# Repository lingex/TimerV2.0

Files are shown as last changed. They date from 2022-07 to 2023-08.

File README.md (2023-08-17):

# TimerV2.0
A kittchen timer, mp3 player. STM32F103RET6, W25Q128, RX8025T, NS4168.  

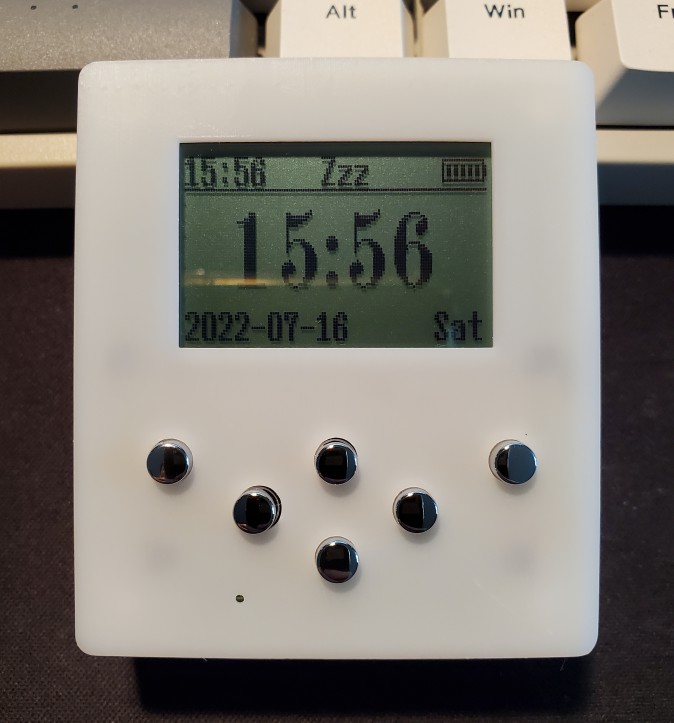
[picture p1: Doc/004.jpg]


## Feature
- software decode mp3, i2s output.  
- 16MB spi flash disk.  
- FATFS format.  
- DFU Bootloader.  

## Known issues  
- The USBLC6 (D1) will cost leakage when USB is not connect, can be avoid by disable the 'USB_EN' pin or simply cut the 5' pin of this component.  
- ~~USB disconnect interrupt can't be detected while device in sleep mode, may fix later.~~  
- ~~Sometimes return to main UI from the setting menu without expected, may fix later.~~  
- I2S stream CLK has to be set as a half of the real sample rate.  
- The NS4168 may cost about 2 mA current, not 1 uA provided by the datasheet.  

## Note  
- This mp3 decode solution is a limited demo, don't use for any business application.  
- More info can be found here:  
- TimerV2.0/TimerApp/Middlewares/ST/STM32_Audio/Codecs/SpiritDSP_MP3_Dec/Release_Notes.html  
- TimerV2.0/TimerApp/Middlewares/ST/STM32_Audio/Codecs/SpiritDSP_MP3_Dec/doc/SpiritMP3Dec_UG.pdf  

### About the '.dfu' file:  
- ST DFU device can be flash by DfuSe or STM32CubeProgrammer  
- The STM32CubeProgrammer supports both '.bin' and '.hex' file.  
- DfuSe supports '.dfu' file only, so you have to convert the '.bin' or '.hex' file into a '.dfu'.  
- To generate a '.dfu' file, there are some ways: like DfuFileMgr.exe(provide by ST), and some third-part tools like hex2dfu.exe.

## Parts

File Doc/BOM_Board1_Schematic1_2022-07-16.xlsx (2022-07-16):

No. | Quantity | Device | Designator | Footprint | Value
1 | 1 | 1056TR | BT1 | BAT-SMD_BD15.0-P18.80
2 | 17 | CAP_0603 | C1,C4,C5,C6,C9,C10,C12,C13,C14,C15,C16,C24,C25,C26,C27,C28,C29 | C0603 | 100nF
3 | 2 | CAP_0603 | C2,C3 | C0603 | 22pF
4 | 3 | CAP_0603 | C7,C11,C17 | C0603 | 1uF
5 | 1 | CAP_0805 | C8 | C0805 | 1uF
6 | 4 | CAP_0805 | C18,C19,C21,C23 | C0805 | 10uF
7 | 1 | C_Ele_SMD_5x5.4mm | C20 | CAP-SMD_BD5.0-L5.3-W5.3-LS6.3-FD | 100uF
8 | 1 | CAP_0805 | C22 | C0805 | 4.7uF
9 | 1 | USBLC6-2SC6 | D1 | SOT-23-6_L2.9-W1.6-P0.95-LS2.8-BL
10 | 1 | B5819W-G | D2 | SOD-123_L2.7-W1.6-LS3.7-RD-1
11 | 2 | BAT60B-TP | D3,D4 | SOD-323_L1.8-W1.3-LS2.5-RD
12 | 1 | CESDBLC5V0D3 | E1 | SOD-323_L1.8-W1.3-LS2.5-BI
13 | 1 | HDR-M_2.54_1x6P | H1 | HDR-TH_6P-P2.54-V-M-1
14 | 2 | HDR-M_2.54_1x2P | H2,H3 | HDR-TH_2P-P2.54-V-M-1
15 | 1 | LED_0805-R | LED1 | LED0805-RD_RED
16 | 1 | LED_0805-G | LED2 | LED0805-RD_RED
17 | 1 | JLX12864G-086-PN | M1 | JLX12864G-086-PN
18 | 3 | SI2301 | Q1,Q2,Q3 | SOT-23_L2.9-W1.3-P1.90-LS2.4-BR
19 | 1 | Res_0603 | R1 | R0603 | 1K5
20 | 2 | Res_0603 | R2,R3 | R0603 | 22R
21 | 3 | Res_0603 | R4,R5,R10 | R0603 | 5K1
22 | 9 | Res_0603 | R6,R7,R13,R32,R33,R34,R35,R36,R37 | R0603 | 36K
23 | 3 | Res_0603 | R8,R17,R21 | R0603 | 100R
24 | 1 | Res_0603 | R9 | R0603 | 220R
25 | 7 | Res_0603 | R11,R16,R19,R20,R22,R23,R30 | R0603 | 10K
26 | 7 | Res_0603 | R12,R24,R25,R26,R27,R28,R29 | R0603 | 1K
27 | 2 | Res_0603 | R14,R15 | R0603 | 4K7
28 | 1 | Res_0603 | R18 | R0603 | 7K5
29 | 1 | AR05DTCW1002 | R31 | R0805 | 0R
30 | 6 | SMD Tactile Switch6*6*6mm | SW1,SW2,SW3,SW4,SW5,SW6 | 6X6按键SMD
31 | 1 | STM32F103RET6 | U1 | LQFP-64_L10.0-W10.0-P0.50-LS12.0-BL
32 | 1 | 25Q128 | U2 | SOIC5.2*8
33 | 1 | TP4057 | U3 | SOT-23-6_L2.9-W1.6-P0.95-LS2.8-BR
34 | 1 | RX-8025T | U4 | SOP-14_L10.1-W5.0-P1.27-LS7.4-BL
35 | 1 | ME6209A33PG | U5 | SOT-89-3_L4.5-W2.5-P1.50-LS4.2-BR
36 | 1 | NS4168 | U6 | ESOP-8_L4.9-W3.9-P1.27-LS6.0-BL-EP-1
37 | 1 | TYPEC-304-BCP16 | USB1 | USB-C-SMD_TYPEC-304-BCP16
38 | 1 | X50328MSB2GI | X1 | CRYSTAL-SMD_L5.0-W3.2 | 8MHz

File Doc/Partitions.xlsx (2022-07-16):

ADDRESS | NAME | SIZE
0x8000000 | Bootloader | 64K
0x8010000 | App | 448K

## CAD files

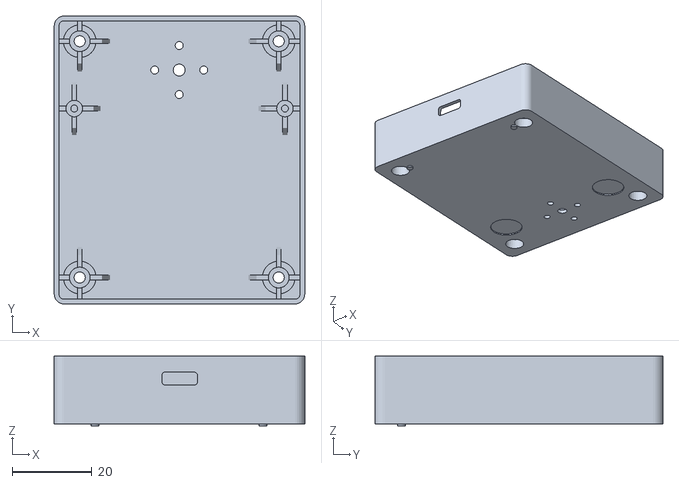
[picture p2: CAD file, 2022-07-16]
Doc/PCB1_B.stl
62.8 x 72.2 x 17.5

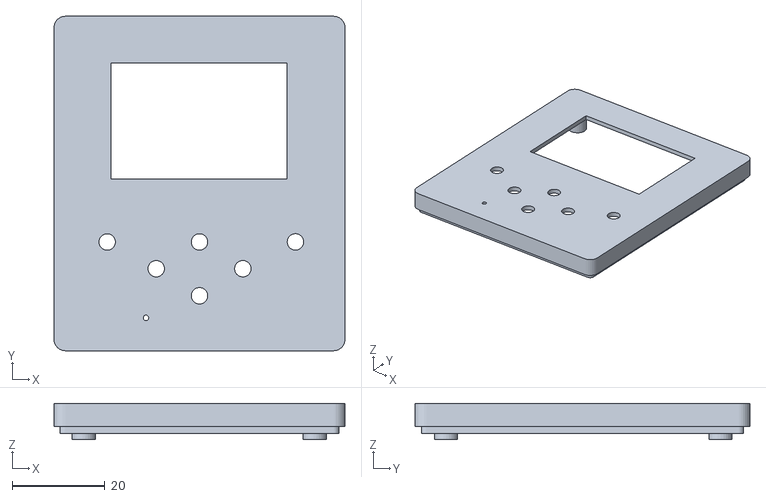
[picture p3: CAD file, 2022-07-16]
Doc/PCB1_T.stl
62.8 x 72.2 x 7.80

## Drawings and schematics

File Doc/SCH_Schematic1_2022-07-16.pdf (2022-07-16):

SBU2 B8 DN2 B7 DP2 B6 CC2 B5 VBUS B4A9 GND B1A12 SBU1 A8 DN1 A7 DP1 A6 CC1 A5 VBUS A4B9 GND A1B12

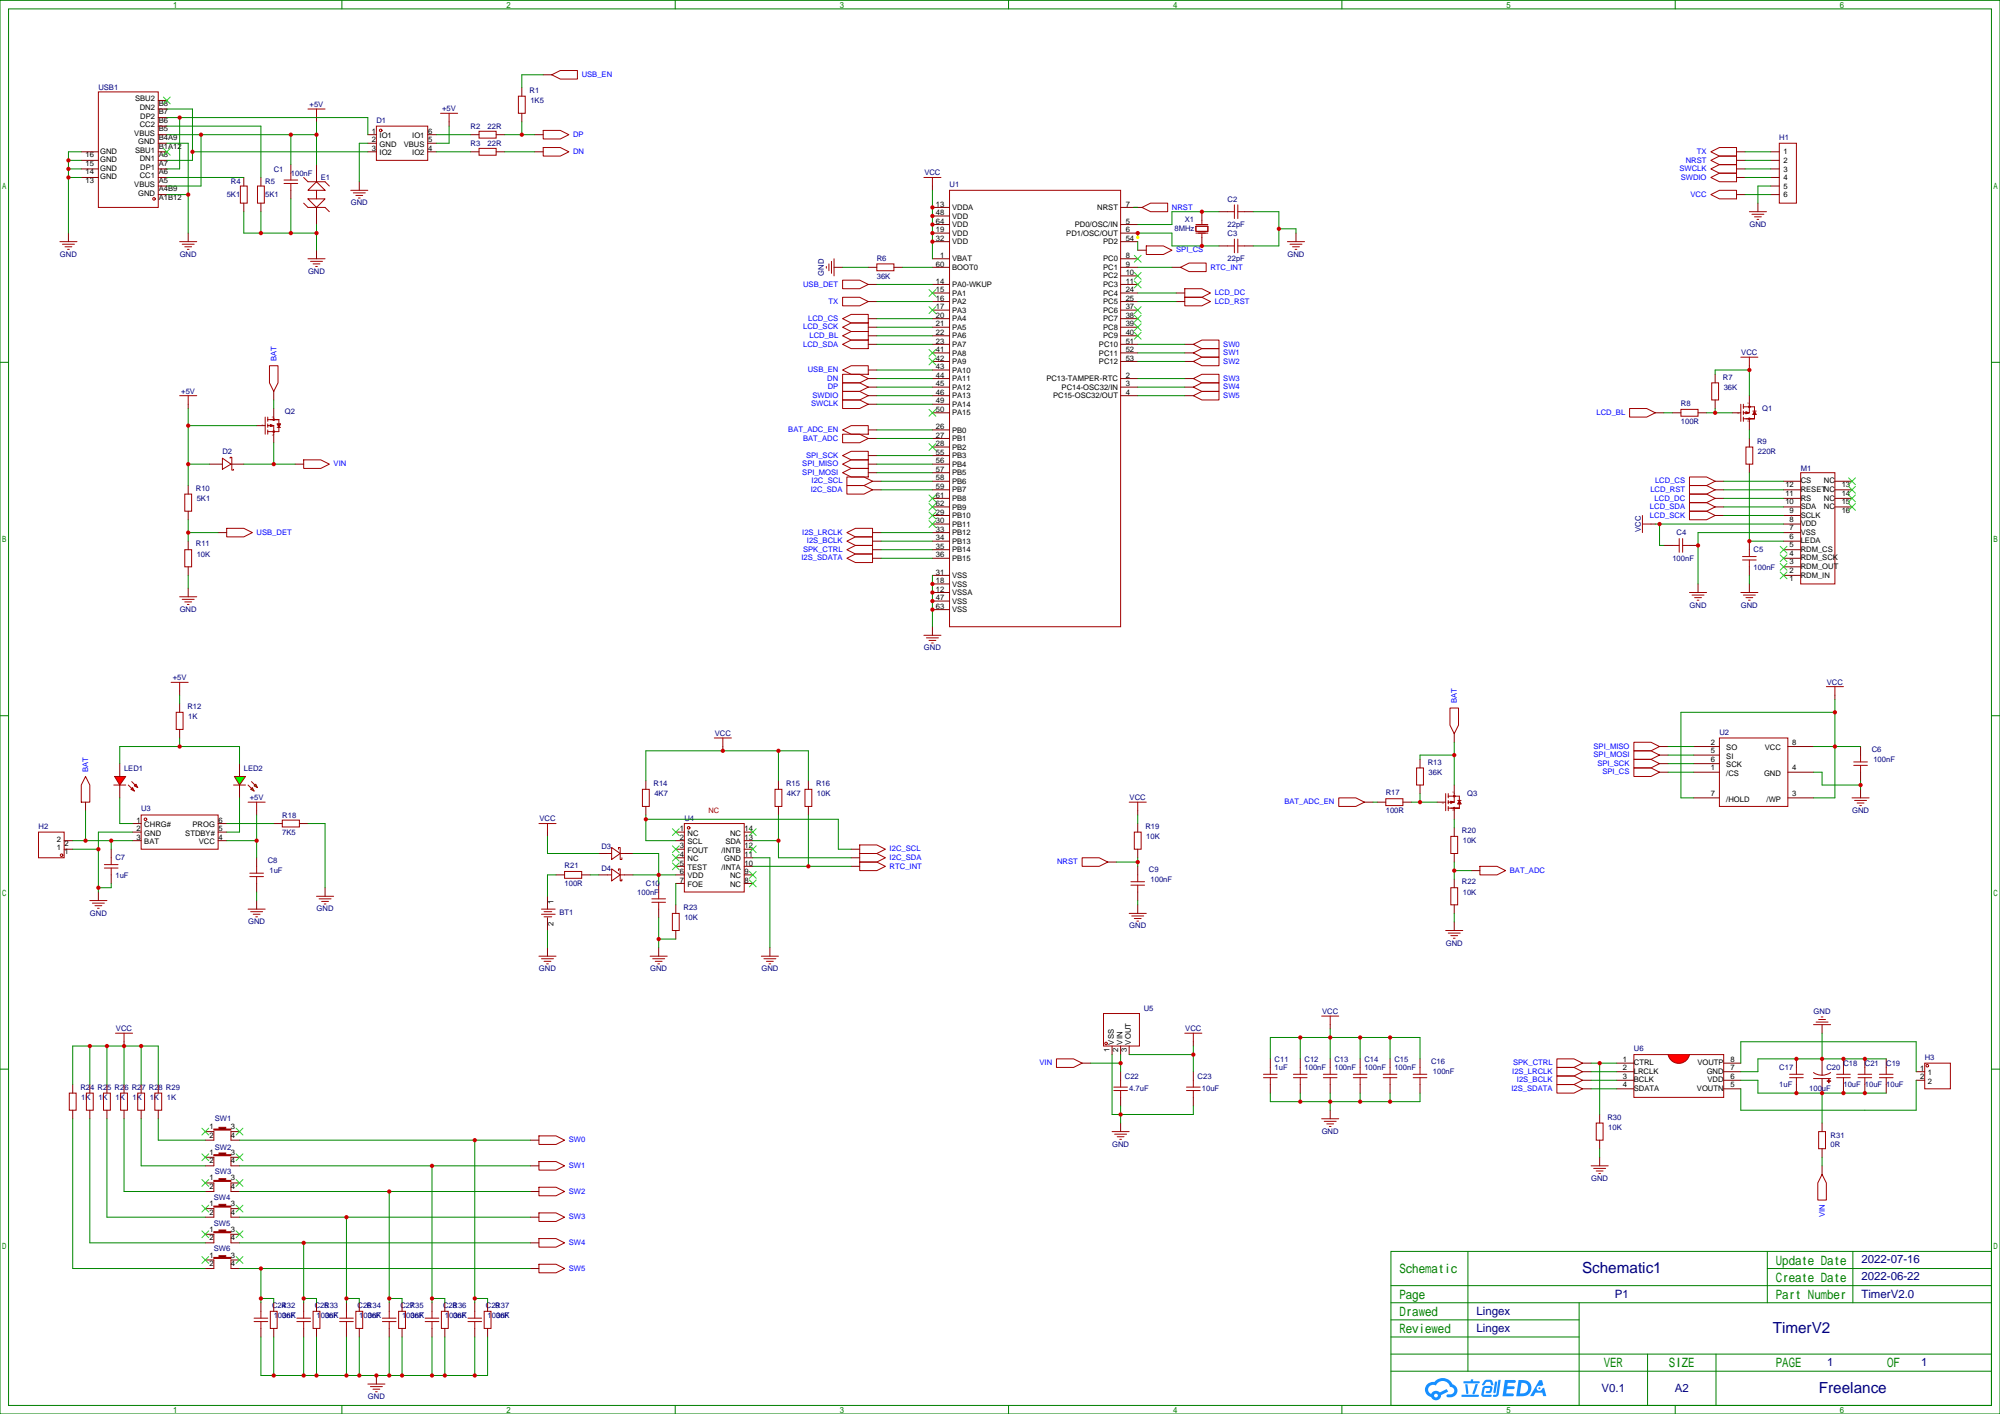
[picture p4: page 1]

GND 16 GND 15 GND 14 GND 13

/INTA 10 GND 11 /INTB 12 SDA 13 NC 14

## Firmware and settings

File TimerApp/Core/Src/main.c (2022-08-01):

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
/* Includes ------------------------------------------------------------------*/
#include "main.h"
#include "fatfs.h"
#include "usb_device.h"

 ADC_HandleTypeDef hadc1;

CRC_HandleTypeDef hcrc;

I2C_HandleTypeDef hi2c1;

I2S_HandleTypeDef hi2s2;
DMA_HandleTypeDef hdma_spi2_tx;

SPI_HandleTypeDef hspi1;
SPI_HandleTypeDef hspi3;
DMA_HandleTypeDef hdma_spi3_tx;
DMA_HandleTypeDef hdma_spi3_rx;

UART_HandleTypeDef huart2;

void SystemClock_Config(void);
static void MX_GPIO_Init(void);
static void MX_ADC1_Init(void);
static void MX_I2C1_Init(void);
static void MX_I2S2_Init(void);
static void MX_SPI1_Init(void);
static void MX_SPI3_Init(void);
static void MX_DMA_Init(void);
static void MX_CRC_Init(void);
static void MX_USART2_UART_Init(void);
/**
  * @brief  The application entry point.
  * @retval int
  */

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
/* USER CODE BEGIN 4 */

void InitProc(void)
{
	SystemClock_Config();

	//spi & i2s dma will not work without this
	MX_DMA_Init();

	/* Initialize all configured peripherals */
	MX_GPIO_Init();
	MX_ADC1_Init();
	MX_I2C1_Init();
	MX_I2S2_Init();
	MX_SPI1_Init();
	MX_SPI3_Init();
	//MX_DMA_Init();
	MX_USB_DEVICE_Init();
	MX_CRC_Init();
	MX_USART2_UART_Init();
	MX_FATFS_Init();
}

void ADC_Config(void)
{
	MX_ADC1_Init();
}

/* USER CODE END 4 */
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


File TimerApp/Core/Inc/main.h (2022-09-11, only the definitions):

#define BTN_DOWN_Pin GPIO_PIN_13
#define BTN_DOWN_GPIO_Port GPIOC
#define BTN_DOWN_EXTI_IRQn EXTI15_10_IRQn
#define BTN_LEFT_Pin GPIO_PIN_14
#define BTN_LEFT_GPIO_Port GPIOC
#define BTN_LEFT_EXTI_IRQn EXTI15_10_IRQn
#define BTN_ESC_Pin GPIO_PIN_15
#define BTN_ESC_GPIO_Port GPIOC
#define BTN_ESC_EXTI_IRQn EXTI15_10_IRQn
#define RTC_INT_Pin GPIO_PIN_1
#define RTC_INT_GPIO_Port GPIOC
#define RTC_INT_EXTI_IRQn EXTI1_IRQn
#define USB_DET_Pin GPIO_PIN_0
#define USB_DET_GPIO_Port GPIOA
#define USB_DET_EXTI_IRQn EXTI0_IRQn
#define LCD_CS_Pin GPIO_PIN_4
#define LCD_CS_GPIO_Port GPIOA
#define LCD_BL_Pin GPIO_PIN_6
#define LCD_BL_GPIO_Port GPIOA
#define LCD_DC_Pin GPIO_PIN_4
#define LCD_DC_GPIO_Port GPIOC
#define LCD_RST_Pin GPIO_PIN_5
#define LCD_RST_GPIO_Port GPIOC
#define BAT_ADC_EN_Pin GPIO_PIN_0
#define BAT_ADC_EN_GPIO_Port GPIOB
#define BAT_ADC_Pin GPIO_PIN_1
#define BAT_ADC_GPIO_Port GPIOB
#define SPK_EN_Pin GPIO_PIN_14
#define SPK_EN_GPIO_Port GPIOB
#define USB_EN_Pin GPIO_PIN_10
#define USB_EN_GPIO_Port GPIOA
#define BTN_GO_Pin GPIO_PIN_10
#define BTN_GO_GPIO_Port GPIOC
#define BTN_GO_EXTI_IRQn EXTI15_10_IRQn
#define BTN_UP_Pin GPIO_PIN_11
#define BTN_UP_GPIO_Port GPIOC
#define BTN_UP_EXTI_IRQn EXTI15_10_IRQn
#define BTN_RIGHT_Pin GPIO_PIN_12
#define BTN_RIGHT_GPIO_Port GPIOC
#define BTN_RIGHT_EXTI_IRQn EXTI15_10_IRQn
#define SPI_CS_Pin GPIO_PIN_2
#define SPI_CS_GPIO_Port GPIOD
#define MUSIC_MAX 32
#define MUSIC_FILE_NAME_LEN 32
#define BL_BRIGHTNESS_ON 1
#define BL_BRIGHTNESS_OFF 0
#define BTN_VAL_GO 		0x0001
#define BTN_VAL_ESC 	0x0002
#define BTN_VAL_UP 		0x0004
#define BTN_VAL_DOWN 	0x0008
#define BTN_VAL_LEFT 	0x0010
#define BTN_VAL_RIGHT 	0x0020
#define WKUP_REASON_POWER 0x0001
#define WKUP_REASON_BTN   0x0002
#define WKUP_REASON_RTC   0x0004
#define WKUP_REASON_USB   0x0008
#define HARDWARE_VERSION "V2.0"
#define FIRMWARE_VERSION "V2.6"
#define APP_BOOTLOADER_ADDR (FLASH_BASE | 0x0000)
#define APP_TIMER_ADDR (FLASH_BASE | 0x10000)

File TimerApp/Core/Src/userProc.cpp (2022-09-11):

#include "main.h"
#include "fatfs.h"
#include "usb_device.h"
#include "player.h"
#include "spi_flash.h"
#include "lcd.h"
#include "rx8025t.h"
#include "menu.h"
#include "config.h"
#include <time.h>
#include "printf.h"

typedef void (*pFunction)(void);
#define LCD_BACKLIGHT(val) (HAL_GPIO_WritePin(LCD_BL_GPIO_Port, LCD_BL_Pin, val > 0 ? GPIO_PIN_RESET : GPIO_PIN_SET))
#define USB_EN(val) (HAL_GPIO_WritePin(USB_EN_GPIO_Port, USB_EN_Pin, val > 0 ? GPIO_PIN_SET : GPIO_PIN_RESET))
#define BAT_ADC_EN(val) (HAL_GPIO_WritePin(BAT_ADC_EN_GPIO_Port, BAT_ADC_EN_Pin, val != 0 ? GPIO_PIN_RESET : GPIO_PIN_SET))

#define USB_DET ((HAL_GPIO_ReadPin(USB_DET_GPIO_Port, USB_DET_Pin) == GPIO_PIN_SET) ? 1 : 0)

#define MENU_TIMEOUT 30
#define SLEEP_TIMEOUT 10
#define BL_TIMEOUT 8

extern UART_HandleTypeDef huart2;
extern SPI_HandleTypeDef hspi1;
extern I2S_HandleTypeDef hi2s2;
extern I2C_HandleTypeDef hi2c1;
extern ADC_HandleTypeDef hadc1;

__IO uint32_t btnVal = 0;
__IO uint8_t usbDet = 0;
uint32_t batVoltage = 0;
uint8_t musicVolume = 95;
uint8_t sleepDispEn = 0;
DevState_t devState = DevStateStandby;
__IO uint32_t wkupReason = WKUP_REASON_POWER;
RTC_WKUP_INTERVAL_t wkupInterval = RTC_WKUP_SEC;
uint32_t currTime = 0;
uint32_t lcdBLTimeout = 0;
uint32_t menuTimeout = 0;
uint32_t sleepTimeout = 0;
uint8_t lcdUpdate = 0;

FATFS FatFs;
u8g2_t u8g2;
char tmpstr[] = "\0\0\0\0\0\0\0\0\0\0\0\0\0\0\0\0\0\0\0\0\0\0\0\0\0\0\0\0\0\0\0\0\0\0\0\0\0\0\0\0\0\0\0\0\0\0\0\0\0\0\0\0\0\0\0\0\0\0\0\0\0\0\0";
char musicUsing[] = "\0\0\0\0\0\0\0\0\0\0\0\0\0\0\0\0\0\0\0\0\0\0\0\0\0\0\0\0\0\0\0\0\0\0\0\0\0\0\0\0\0\0\0\0\0\0\0\0\0\0\0\0\0\0\0\0\0\0\0\0\0\0\0";
const char *builtTime = __DATE__ "," __TIME__;

_RTC rtc = {
	.Year = 22, .Month = 7, .Date = 3, .DaysOfWeek = SUNDAY, .Hour = 13, .Min = 25, .Sec = 22};

_COUNTER runCounter = {
	.Hour = 0, .Min = 5, .Sec = 0};

Player player(&hi2s2);

void BatteryVoltage(void);
uint32_t GetBatAdc(void);
void TimerProcess(void);
void Sleep(void);
void RtcToTimestamp(void);
void RtcToTm(_RTC *rtc, struct tm *t);
void TimestampToRTC(void);
void PlayerStartCallback(void);
void PlayerStopCallback(void);

void _putchar(char character)
{
	HAL_UART_Transmit(&huart2, (uint8_t*)&character, 1, 5);
}

int main(void)
{
	SCB->VTOR = APP_TIMER_ADDR;

	/* MCU Configuration--------------------------------------------------------*/

	/* Reset of all peripherals, Initializes the Flash interface and the Systick. */
	HAL_Init();

	InitProc();
	W25QXX_WAKEUP();

	printf_("Starting, tick: %lu.\n", HAL_GetTick());
	printf_("Hardware: %s.\n", HARDWARE_VERSION);
	printf_("Firmware: %s.\n", FIRMWARE_VERSION);
	printf_("Built: %s.\n\n", builtTime);

	LCD_BACKLIGHT(BL_BRIGHTNESS_ON);
	usbDet = USB_DET;
	if (usbDet == 1)
	{
		USB_EN(1);
	}
	printf_("Init LCD, tick: %lu.\n", HAL_GetTick());
	u8g2Init(&u8g2, &hspi1);
	u8g2_DrawLine(&u8g2, 0, 11, 127, 11);
	u8g2_SetFont(&u8g2, u8g2_font_7x14B_tr);
	sprintf_(tmpstr, "Timer V2.0");
	u8g2_DrawStr(&u8g2, 28, 10, tmpstr);
	u8g2_SendBuffer(&u8g2);
	HAL_Delay(500);

	printf_("Init FATFS, tick: %lu.\n", HAL_GetTick());
	FRESULT rc = f_mount(&FatFs, "", 0);
	if (rc != FR_OK)
	{
		printf_("FATFS mount failed! tick: %lu.\n", HAL_GetTick());
		//return rc;
	}
	printf_("Init config, tick: %lu.\n", HAL_GetTick());
	LoadConfigs();

	printf_("Init player, tick: %lu.\n", HAL_GetTick());

	player.SetVolume(musicVolume);

	printf_("Init RTC, tick: %lu.\n", HAL_GetTick());
	RX8025T_Init(&hi2c1);
	RX8025T_SetINTPerSec();
	// RX8025T_SetINTPerMin();
	//RX8025T_SetTime(&rtc);
	RtcToTimestamp();
	printf_("Timestamp: %lu, tick: %lu.\n", currTime, HAL_GetTick());

	lcdBLTimeout = currTime + BL_TIMEOUT;
	sleepTimeout = currTime + SLEEP_TIMEOUT;

	BatteryVoltage();
	printf_("Battery voltage: %lu mV, tick: %lu.\n\n", batVoltage, HAL_GetTick());

	printf_("Loop start, tick: %lu.\n\n", HAL_GetTick());
	//DispUpdate();

	//PlayerStart("test.MP3");
	//PlayerStart("Take my breath away.mp3");
	//W25QXX_Erase_Chip();

  /* Infinite loop */

  while (1)
  {
	if (wkupReason != 0)
	{
		//printf_("wkup:%#06x\n", wkupReason);

		if ((wkupReason & WKUP_REASON_RTC) != 0)
		{
#if 0	//counter
			currTime++;
			TimestampToRTC();
#else	//RTC
			RtcToTimestamp();
#endif
			if (devState == DevStateTimerRun)
			{
				TimerProcess();
			}
			BatteryVoltage();
			lcdUpdate = 1;
		}
		if ((wkupReason & WKUP_REASON_BTN) != 0)
		{
			if (wkupInterval != RTC_WKUP_SEC && (wkupReason & WKUP_REASON_RTC) == 0)
			{
				RtcToTimestamp();
			}

			lcdBLTimeout = currTime + BL_TIMEOUT;
			LCD_BACKLIGHT(BL_BRIGHTNESS_ON);
			if (wkupInterval != RTC_WKUP_SEC)
			{
				wkupInterval = RTC_WKUP_SEC;
				RX8025T_SetINTPerSec();
			}
			OnBtnDown(btnVal);
			if (devState == DevStateTimerRun || devState == DevStateMenuMusic)
			{
				menuTimeout = 0;
				sleepTimeout = 0;
			}
			else
			{
				sleepTimeout = 0;
				menuTimeout = currTime + MENU_TIMEOUT;
			}
			btnVal = 0;
			lcdUpdate = 1;
		}
		if ((wkupReason & WKUP_REASON_USB) != 0)
		{
			if (devState == DevStateSleep)
			{
				devState = DevStateStandby;
				menuTimeout = currTime + MENU_TIMEOUT;
			}
			RtcToTimestamp();
			lcdBLTimeout = currTime + BL_TIMEOUT;
			LCD_BACKLIGHT(BL_BRIGHTNESS_ON);
			if (wkupInterval != RTC_WKUP_SEC)
			{
				wkupInterval = RTC_WKUP_SEC;
				RX8025T_SetINTPerSec();
			}
			if (usbDet == 1)
			{
				if (player.IsBusy())
				{
					player.Stop();
				}
				if (W25QXX_GetPowerState() == 0)
				{
					W25QXX_WAKEUP();
				}
				USB_EN(1);
			}
			else
			{
				USB_EN(0);
				if (W25QXX_GetPowerState() != 0 && !player.IsBusy())
				{
					W25QXX_PowerDown();
				}
			}
			lcdUpdate = 1;
		}
		if ((wkupReason & WKUP_REASON_POWER) != 0)
		{
			lcdUpdate = 1;
		}
		wkupReason = 0;
	}

	if (lcdBLTimeout > 0 && currTime >= lcdBLTimeout)
	{
		lcdBLTimeout = 0;
		LCD_BACKLIGHT(BL_BRIGHTNESS_OFF);
	}
	if (menuTimeout > 0 && currTime >= menuTimeout)
	{
		menuTimeout = 0;
		sleepTimeout = currTime + SLEEP_TIMEOUT;
		devState = DevStateStandby;
		lcdUpdate = 1;
	}
	if (sleepTimeout > 0 && currTime >= sleepTimeout)
	{
		sleepTimeout = 0;
		devState = DevStateSleep;
		if (W25QXX_GetPowerState() != 0 && usbDet == 0)
		{
			W25QXX_PowerDown();
		}
		lcdUpdate = 1;
	}
	if (lcdUpdate != 0)
	{
		lcdUpdate = 0;
		DispUpdate();
	}
	if (player.IsBusy())
	{
		player.Tick();
	}

	if (!player.IsBusy() && usbDet == 0 && devState == DevStateSleep && wkupReason == 0)
	{
		LCD_BACKLIGHT(BL_BRIGHTNESS_OFF);

		if (sleepDispEn == 0)
		{
			wkupInterval = RTC_WKUP_DISABLE;
			RX8025T_SetINTDisable();
		}
		else
		{
			if (wkupInterval != RTC_WKUP_MIN)
			{
				wkupInterval = RTC_WKUP_MIN;
				RX8025T_SetINTPerMin();
			}
		}
		if (W25QXX_GetPowerState() != 0)
		{
			W25QXX_PowerDown();
		}

		//printf_("Sleep: %02d:%02d:%02d, tick:%lu.\n", rtc.Hour, rtc.Min, rtc.Sec, HAL_GetTick());
		Sleep();
		//printf_("Wkup: %02d:%02d:%02d, tick:%lu.\n", rtc.Hour, rtc.Min, rtc.Sec, HAL_GetTick());
	}
  }
}
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

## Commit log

2022-07-11 init repo
    [stlink.cfg, stm32f1x.cfg]
2022-07-16 low power action
2022-07-16 some doc
    [BOM_Board1_Schematic1_2022-07-16.xlsx, PCB1_B.stl, PCB1_T.stl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]
2022-07-21 fix USB detect bug in sleep mode, some other optimize
    [main.c, main.h, player.c]
2022-07-23 lower CLK speed, reduce power cost
2022-07-30 fix music selecting menu bug
    [main.c]
2022-08-01 define speaker power
2022-09-11 lower power, display off while sleeping
2022-09-11 display wake up on charging
2022-09-11 display or not while sleep can be change in the config file (a reboot is required)
    [main.h, userProc.cpp]
2026-06-08 update hal drivers, add cmake
2026-07-13 spi flash can be used while charging

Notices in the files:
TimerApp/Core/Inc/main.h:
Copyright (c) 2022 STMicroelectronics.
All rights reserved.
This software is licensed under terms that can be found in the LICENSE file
